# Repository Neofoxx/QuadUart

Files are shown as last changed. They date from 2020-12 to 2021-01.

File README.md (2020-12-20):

# QuadUart
A Quad UART to USB converter, based on PIC32.

## Overview

This project uses a PIC32MX564F128H micro to implement a quad UART-USB converter. The idea is to use an open-source toolchain to create a useful project, and one can **never** have too many UART converters

At least 4x 115200bps is supported, with plans to go to 4x 1Mbps, speed of the micro permitting.

Exposed pins are TX, RX, and DTR.

## Toolchain

The entire toolchain is open source:
- MCU definitions from the [SpicaStack](https://gitlab.com/spicastack/pic32-parts-free) project
- Compiler is GCC for mipsel crosscompiling. A ready-to-go package can be found [here](https://build.opensuse.org/package/show/home:neofoxx/gcc-mipsel-elf) (Ubuntu, Fedora, OpenSuse packges currently built)
- The USB stack is [M-stack](https://github.com/signal11/m-stack)
- PCB is provided as a set of Gerber files, and as a KiCAD project.

## TODO

- Add fiducails to PCB
- Add pinout to Readme
- License

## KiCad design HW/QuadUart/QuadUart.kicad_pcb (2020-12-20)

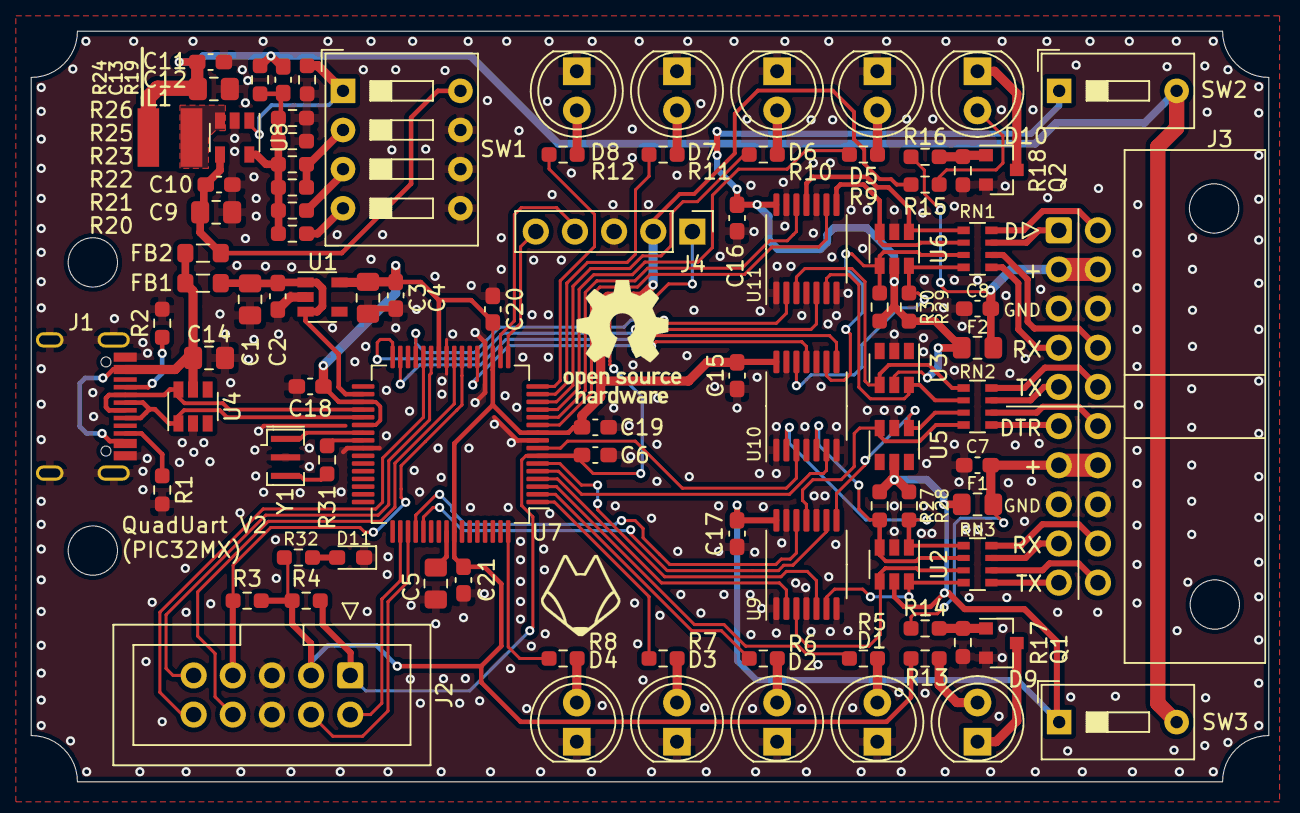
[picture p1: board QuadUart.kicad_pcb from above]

Board: 2 copper layers, 80.3 x 48.7 mm, 100 parts (1 on the bottom side), 92 nets.

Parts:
C1, C3, C9, C12: 4.7uF; C_0805_2012Metric_Pad1.18x1.45mm_HandSolder
C2, C4, C6, C7, C8, C10, C11, C15, C16, C17, C18, C19, C20, C21: 100nF; C_0603_1608Metric_Pad1.08x0.95mm_HandSolder
C5, C14: 10uF; C_0805_2012Metric_Pad1.18x1.45mm_HandSolder
C13: DNS; C_0603_1608Metric_Pad1.08x0.95mm_HandSolder
D1, D2, D3, D4, D5, D6, D7, D8, D9, D10: LED; LED_D5.0mm
D11: LED; LED_0603_1608Metric_Pad1.05x0.95mm_HandSolder
F1, F2: Polyfuse; Fuse_0805_2012Metric_Pad1.15x1.40mm_HandSolder
FB1, FB2: Ferrite_Bead_Small; L_0805_2012Metric_Pad1.05x1.20mm_HandSolder
H1, H2, H3, H4: MountingHole; MountingHole_3.2mm_M3
J1: USB_C_Receptacle_USB2.0; Jing USB C 2.0 16pin receptable
J2: Conn_02x05_Odd_Even; IDC-Header_2x05_P2.54mm_Vertical
J3: Conn_02x10_Odd_Even; IDC-Header_2x10_P2.54mm_Horizontal
J4: Conn_01x05; PinHeader_1x05_P2.54mm_Vertical
L1: 1.5uH; SMNR4018_(1616FPS)
LOGO1: Logo_Open_Hardware_Small; OSHW-Logo_7.5x8mm_SilkScreen
MARK1: LOGO; FOX_LOGO_MASK
MARK2: LOGO; FOX_LOGO_SILK
Q1, Q2: BC847; SOT-23
R1, R2: 5.1k; R_0603_1608Metric_Pad0.98x0.95mm_HandSolder
R3, R4, R19: 100k; R_0603_1608Metric_Pad0.98x0.95mm_HandSolder
R5, R6, R7, R8, R9, R10, R11, R12, R13, R15, R32: R; R_0603_1608Metric_Pad0.98x0.95mm_HandSolder
R14, R16, R17, R18: 10k; R_0603_1608Metric_Pad0.98x0.95mm_HandSolder
R20: 27k; R_0603_1608Metric_Pad0.98x0.95mm_HandSolder
R21: 180k; R_0603_1608Metric_Pad0.98x0.95mm_HandSolder
R22: 470k; R_0603_1608Metric_Pad0.98x0.95mm_HandSolder
R23: 330k; R_0603_1608Metric_Pad0.98x0.95mm_HandSolder
R24, R25, R26, R27, R28, R29, R30: 220k; R_0603_1608Metric_Pad0.98x0.95mm_HandSolder
R31: 0R; R_0603_1608Metric_Pad0.98x0.95mm_HandSolder
RN1, RN2, RN3: R_Pack04; R_Array_Convex_4x0603
SW1: SW_DIP_x04; SW_DIP_SPSTx04_Slide_9.78x12.34mm_W7.62mm_P2.54mm
SW2, SW3: SW_DIP_x01; SW_DIP_SPSTx01_Slide_9.78x4.72mm_W7.62mm_P2.54mm
U1: LN1134-3.3V; SOT-23-5
U2, U3, U4, U5, U6: SRV05-4; SOT-23-6
U7: PIC32MX564F128H; TQFP-64_10x10mm_P0.5mm
U8: BL8028; SOT-23-5
U9, U10, U11: SN74LV4T125; TSSOP-14_4.4x5mm_P0.65mm
Y1: Crystal_GND2; Resonator_SMD_muRata_CSTxExxV-3Pin_3.0x1.1mm

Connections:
+3V3: C3.1, C4.1, C15.1, C18.1, C19.1, C20.1, C21.1, J2.3, J4.2, R3.2, R4.2, R13.2, R15.2, R32.2, U1.5, U7.10, U7.19, U7.26, U7.35, U7.38, U7.57, U10.14
+5V: C1.1, C2.1, FB1.1, U1.1, U1.3, U7.34
/D+: J1.A6, J1.B6, U4.1, U7.37
/D-: J1.A7, J1.B7, U4.6, U7.36
/DTR_1: J3.11, RN2.5
/DTR_1_RES: RN2.4, U5.3, U9.11
/DTR_1_UC: U7.52, U9.12
/DTR_2: J3.12, RN2.6
/DTR_2_RES: RN2.3, U5.1, U9.8
/DTR_2_UC: U7.53, U9.9
/DTR_3: J3.1, RN1.7
/DTR_3_RES: RN1.2, U6.3, U11.8
/DTR_3_UC: U7.11, U11.9
/DTR_4: J3.2, RN1.8
/DTR_4_RES: RN1.1, U6.1, U11.11
/DTR_4_UC: U7.12, U11.12
/EN_1: R19.1, SW1.1, U8.1
/FB_1: C13.2, R20.1, R21.1, R22.1, R23.1, R24.2, R25.1, R26.1, U8.5
/LED_RX_1: R6.2, U7.2
/LED_RX_2: R8.2, U7.64
/LED_RX_3: R10.2, U7.14
/LED_RX_4: R12.2, U7.16
/LED_TX_1: R5.2, U7.3
/LED_TX_2: R7.2, U7.1
/LED_TX_3: R9.2, U7.13
/LED_TX_4: R11.2, U7.15
/OSC1: U7.39, Y1.1
/OSC2: R31.2, U7.40
/PGEC2: J4.5, U7.17
/PGED2: J4.4, U7.18
/PWR_1: C7.1, F1.1, J3.13, J3.14, R14.2
/PWR_2: C8.1, F2.1, J3.3, J3.4, R16.2
/RX_1: J3.17, RN3.7
/RX_1_RES: R27.2, RN3.2, U2.3, U10.5
/RX_1_UC: U7.5, U10.6
/RX_2: J3.18, RN3.8
/RX_2_RES: R28.2, RN3.1, U2.1, U10.2
/RX_2_UC: U7.8, U10.3
/RX_3: J3.7, RN1.5
/RX_3_RES: R29.2, RN1.4, U6.6, U10.12
/RX_3_UC: U7.31, U10.11
/RX_4: J3.8, RN1.6
/RX_4_RES: R30.2, RN1.3, U6.4, U10.9
/RX_4_UC: U7.21, U10.8
/RX_DBG: J2.2, U7.50
/SW_1_2.5V: R22.2, R23.2, SW1.2
/SW_1_3.3V: R21.2, SW1.3
/SW_1_5.0V: R20.2, SW1.4
/TCK: J2.9, U7.27
/TDI: J2.10, U7.28
/TDO: J2.8, U7.24
/TMS: J2.7, R3.1, U7.23
/TX_1: J3.19, RN3.5
/TX_1_RES: RN3.4, U2.6, U9.6
/TX_1_UC: U7.6, U9.5
/TX_2: J3.20, RN3.6
/TX_2_RES: RN3.3, U2.4, U9.3
/TX_2_UC: U7.4, U9.2
/TX_3: J3.9, RN2.7
/TX_3_RES: RN2.2, U3.6, U11.6
/TX_3_UC: U7.32, U11.5
/TX_4: J3.10, RN2.8
/TX_4_RES: RN2.1, U3.4, U11.3
/TX_4_UC: U7.29, U11.2
/TX_DBG: J2.4, U7.51
/VBUS: C14.1, FB1.2, FB2.2, J1.A4, U4.5
/VBUS_DCDC_5V: C9.1, C10.1, FB2.1, SW1.8, U8.4
/VCAP: C5.1, U7.56
/~MCLR~: C6.1, J2.1, J4.1, R4.1, U7.7
GND: C1.2, C2.2, C3.2, C4.2, C5.2, C6.2, C7.2, C8.2, C9.2, C10.2, C11.2, C12.2, C14.2, C15.2, C16.2, C17.2, C18.2, C19.2, C20.2, C21.2, D1.1, D2.1, D3.1, D4.1, D5.1, D6.1, D7.1, D8.1, D11.1, J1.A1, J1.S1, J2.5, J2.6, J3.5, J3.6, J3.15, J3.16, J4.3, Q1.2, Q2.2, R1.2, R2.2, R17.1, R18.1, R19.2, R25.2, R26.2, SW1.5, SW1.6, SW1.7, U1.2, U2.2, U3.2, U4.2, U5.2, U6.2, U7.9, U7.20, U7.25, U7.41, U8.2, U9.1, U9.4, U9.7, U9.10, U9.13, U10.1, U10.4, U10.7, U10.10, U10.13, U11.1, U11.4, U11.7, U11.10, U11.13, Y1.2
unnamed: C11.1, C12.1, C13.1, L1.2, R24.1, SW2.2, SW3.2
unnamed: D1.2, R5.1
unnamed: D2.2, R6.1
unnamed: D3.2, R7.1
unnamed: D4.2, R8.1
unnamed: D5.2, R9.1
unnamed: D6.2, R10.1
unnamed: D7.2, R11.1
unnamed: D8.2, R12.1
unnamed: D9.1, Q1.3
unnamed: D9.2, R13.1
unnamed: D10.1, Q2.3
unnamed: D10.2, R15.1
unnamed: D11.2, R32.1
unnamed: J1.A5, R2.1
unnamed: J1.B5, R1.1
unnamed: L1.1, U8.3
unnamed: Q1.1, R14.1, R17.2
unnamed: Q2.1, R16.1, R18.2
unnamed: R31.1, Y1.3
VCC: C17.1, F1.2, R27.1, R28.1, SW3.1, U2.5, U5.5, U9.14
VDD: C16.1, F2.2, R29.1, R30.1, SW2.1, U3.5, U6.5, U11.14

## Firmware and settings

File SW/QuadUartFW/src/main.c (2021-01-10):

#include <p32xxxx.h>
#include <inttypes.h>
#include <stdbool.h>
#include <builtin.h>

#include <string.h>
#include <stdio.h>
#include <newlib.h>
#include <errno.h>

// Config bits
#include <configBits.h>

// Drivers for HW
#include <GPIODrv.h>
#include <UARTDrv.h>
//#include <LED.h>
// USB
#include <usb.h>
#include <usb_config.h>
#include <usb_ch9.h>
#include <usb_cdc.h>
// COMMS - usb and UART
#include <COMMS.h>
// Interrupts
#include <interrupt.h>



#ifdef MULTI_CLASS_DEVICE
// Interfaces 0, 2, 4 and 6. Each begins at the IAD, and then goes on for 2 interfaces (0 and 1, 2 and 3, 4 and 5, 6 and 7).
static uint8_t cdc_interfaces[] = { 0, 2, 4, 6 };
#endif

static struct cdc_line_coding line_coding_1 =
{
	115200,
	CDC_CHAR_FORMAT_1_STOP_BIT,
	CDC_PARITY_NONE,
	8,
};

static struct cdc_line_coding line_coding_2 =
{
	115200,
	CDC_CHAR_FORMAT_1_STOP_BIT,
	CDC_PARITY_NONE,
	8,
};

static struct cdc_line_coding line_coding_3 =
{
	115200,
	CDC_CHAR_FORMAT_1_STOP_BIT,
	CDC_PARITY_NONE,
	8,
};

static struct cdc_line_coding line_coding_4 =
{
	115200,
	CDC_CHAR_FORMAT_1_STOP_BIT,
	CDC_PARITY_NONE,
	8,
};



volatile uint32_t packetCounter = 0;	// Reset by SOF. May be useful


// TODO - run the timer, like in MX440 example (SysTick style)
void simpleDelay(unsigned int noOfLoops){
    unsigned int i = 0;
    while (i<noOfLoops){
        i++;
        asm("nop");
    }
}

void setup(){
	// What is the equivalent of SYSTEMConfigPerformance?
	// -> Setting up the system for the required System Clock
	// -> Seting up the Wait States
	// -> Setting up PBCLK
	// -> Setting up Cache module (not presenf on MX1/2, but is on MX4)
	// Also of interest: https://microchipdeveloper.com/32bit:mx-arch-exceptions-processor-initialization
	// See Pic32 reference manual, for CP0 info http://ww1.microchip.com/downloads/en/devicedoc/61113e.pdf

	// DO NOT setup KSEG0 (cacheable area) on MX1/MX2, debugging will NOT work

	unsigned int val;
	val = _CP0_GET_CONFIG();	// Macro present in cp0defs.h
	val |= 0x00000003;	// Sets to KSEG0/cachable region, as per Table 2-11 in ref. manual
	_mtc0(_CP0_CONFIG, _CP0_CONFIG_SELECT, val);	// No macro, do it as suggested in first link.

	BMXCONbits.BMXWSDRM = 0;	// Set wait-states to 0 for Data Memory from SRAM

	CHECONbits.PFMWS = 2;		// Flash requires minimum 2 wait states at 61-80MHz

	CHECONbits.PREFEN = 1;		// Enable prefetch for cacheable PFM instructions

	GPIODrv_init();

	UARTDrv_1_Init(&line_coding_1);
	UARTDrv_2_Init(&line_coding_2);
	UARTDrv_3_Init(&line_coding_3);
	UARTDrv_4_Init(&line_coding_4);

	// Copied for USB, from hardware.c
	// TODO, make generic, make proper.
//#if defined (__32MX270F256D__)
//	IPC7bits.USBIP = 4;
//#elif defined(__32MX440F256H__)
//	IPC11bits.USBIP = 4;
//#endif

	// Enable USB interrupt
	IPC11bits.USBIP = 4;
	IPC11bits.USBIS = 0;
	// IEC bit is set in usb_hal.h


	// Enable DMA at the end.
	//DMACONbits.ON = 1;
	//asm("nop");

	// Enable interrupts - at the end, otherwise setting priorities is ineffective ? TODO

	// set the CP0 cause IV bit high
	// -> This tells the interrupt controller to use interrupts at ebase+0x200,
	// not the general exception at 0x180
	_CP0_BIS_CAUSE(_CP0_CAUSE_IV_MASK);

	// Enable multi-vectored mode
	INTCONSET = _INTCON_MVEC_MASK;

	// set the CP0 status IE bit high to turn on interrupts
	//INTEnableInterrupts();
	asm("ei");	// Compiler handles this, but should be same as _CP0_BIS_STATUS(_CP0_STATUS_IE_MASK)

}


int main(){

	uint32_t lastTime = _CP0_GET_COUNT();
	uint32_t currTime = lastTime;

	setup();
	cdc_set_interface_list(cdc_interfaces, 4);	// 4 UART interfaces...
	usb_init();

	for(;;){

		// Handle data that is to be sent to the PC
		// Nothing yet

		#ifndef USB_USE_INTERRUPTS
		usb_service();
		#endif


		currTime = _CP0_GET_COUNT();
		// Once per ms
		if ((currTime - lastTime) > ( (80000000 / 2) / 1000)){
			lastTime = currTime;
			// Fire ALL the RX interrupts, to get data that doesn't trigger the RX interrupt
			// Note, we will get interrupted by each interrupt
			if(UART_1_STA_bits.URXDA){
				UART_1_INT_IFS_bits.UART_1_INT_IFS_RXIF = 1;
			}
			if(UART_2_STA_bits.URXDA){
				UART_2_INT_IFS_bits.UART_2_INT_IFS_RXIF = 1;
			}
			if(UART_3_STA_bits.URXDA){
				UART_3_INT_IFS_bits.UART_3_INT_IFS_RXIF = 1;
			}
			if(UART_4_STA_bits.URXDA){
				UART_4_INT_IFS_bits.UART_4_INT_IFS_RXIF = 1;
			}

		}

	}

    return(0);
    
}




/////////////////////////////////////////////////////////////7

#ifdef USB_USE_INTERRUPTS
INTERRUPT(USB1Interrupt){
	usb_service();

	// All of the cases depend on this anyway.
	if (!usb_is_configured()){
		return;
	}

	// I forget, does this happen at 1ms, or at 125us?
	// 1ms is normal time slice, but we can send many more packets than just 1/ms... TODO check

	// Highest priority should be on Target->PC transmissions, since we can only buffer so much
	// For PC->Target, the USB stack auto-buffers, so there will be no dropouts

	// Total of 4 IN endpoints (Target->PC), and 4 OUT endpoints (PC->TARGET)

	// IN endpoints
	if (!usb_in_endpoint_halted(EP_UART_1) && !usb_in_endpoint_busy(EP_UART_1)){
		COMMS_USB_sendToPC(&comStruct_UART_1_RX, EP_UART_1, EP_UART_1_LEN);
	}
	if (!usb_in_endpoint_halted(EP_UART_2) && !usb_in_endpoint_busy(EP_UART_2)){
		COMMS_USB_sendToPC(&comStruct_UART_2_RX, EP_UART_2, EP_UART_2_LEN);
	}
	if (!usb_in_endpoint_halted(EP_UART_3) && !usb_in_endpoint_busy(EP_UART_3)){
		COMMS_USB_sendToPC(&comStruct_UART_3_RX, EP_UART_3, EP_UART_3_LEN);
	}
	if (!usb_in_endpoint_halted(EP_UART_4) && !usb_in_endpoint_busy(EP_UART_4)){
		COMMS_USB_sendToPC(&comStruct_UART_4_RX, EP_UART_4, EP_UART_4_LEN);
	}

	// OUT endpoints
	// When we get data, if TX interrupt isn't running, we reenable it. Note, that will interurpt us here.
	if (!usb_out_endpoint_halted(EP_UART_1) && usb_out_endpoint_has_data(EP_UART_1) && !usb_in_endpoint_busy(EP_UART_1)) {
		if(!COMMS_USB_recvFromPC(&comStruct_UART_1_TX, EP_UART_1)){
			if (!UART_1_INT_IEC_bits.UART_1_INT_IEC_TXIE){
				UART_1_INT_IEC_bits.UART_1_INT_IEC_TXIE = 1;
			}
		}
	}
	if (!usb_out_endpoint_halted(EP_UART_2) && usb_out_endpoint_has_data(EP_UART_2) && !usb_in_endpoint_busy(EP_UART_2)) {
		if(!COMMS_USB_recvFromPC(&comStruct_UART_2_TX, EP_UART_2)){
			if (!UART_2_INT_IEC_bits.UART_2_INT_IEC_TXIE){
				UART_2_INT_IEC_bits.UART_2_INT_IEC_TXIE = 1;
			}
		}
	}
	if (!usb_out_endpoint_halted(EP_UART_3) && usb_out_endpoint_has_data(EP_UART_3) && !usb_in_endpoint_busy(EP_UART_3)) {
		if(!COMMS_USB_recvFromPC(&comStruct_UART_3_TX, EP_UART_3)){
			if (!UART_3_INT_IEC_bits.UART_3_INT_IEC_TXIE){
				UART_3_INT_IEC_bits.UART_3_INT_IEC_TXIE = 1;
			}
		}
	}
	if (!usb_out_endpoint_halted(EP_UART_4) && usb_out_endpoint_has_data(EP_UART_4) && !usb_in_endpoint_busy(EP_UART_4)) {
		if(!COMMS_USB_recvFromPC(&comStruct_UART_4_TX, EP_UART_4)){
			if (!UART_4_INT_IEC_bits.UART_4_INT_IEC_TXIE){
				UART_4_INT_IEC_bits.UART_4_INT_IEC_TXIE = 1;
			}
		}
	}

}
#endif


/* Callbacks. These function names are set in usb_config.h. */
void app_set_configuration_callback(uint8_t configuration)
{

}

uint16_t app_get_device_status_callback()
{
	return 0x0000;
}

void app_endpoint_halt_callback(uint8_t endpoint, bool halted){
	// This is a notification only.  There is no way to reject this request.
}

int8_t app_set_interface_callback(uint8_t interface, uint8_t alt_setting){
	// The callback should return 0 if the new alternate setting can be set or -1 if
	// it cannot. This callback is completely unnecessary if you only have one
	// alternate setting (alternate setting zero) for each interface.
	return 0;
}

int8_t app_get_interface_callback(uint8_t interface){
	// The application should return the interface's current alternate setting
	return 0;
}

void app_out_transaction_callback(uint8_t endpoint){
	// If we wanted, we can use this function to trigger when the
	// OUT transaction on the endpoint is finished (PC->us), and read
	// data out fast that way. Unnecessary for now.
}

void app_in_transaction_complete_callback(uint8_t endpoint){
	// If we wanted, we can use this function to trigger when the
	// IN transaction on the endpoint is finished (us->PC), and rearm/send
	// data fast that way. Unnecessary for now.
}

int8_t app_unknown_setup_request_callback(const struct setup_packet *setup){
	/* To use the CDC device class, have a handler for unknown setup
	 * requests and call process_cdc_setup_request() (as shown here),
	 * which will check if the setup request is CDC-related, and will
	 * call the CDC application callbacks defined in usb_cdc.h. For
	 * composite devices containing other device classes, make sure
	 * MULTI_CLASS_DEVICE is defined in usb_config.h and call all
	 * appropriate device class setup request functions here.
	 */
	// Since we only use (dual) CDC, cdc_setup_request is enough, it gets called twise.
	return process_cdc_setup_request(setup);
}

int16_t app_unknown_get_descriptor_callback(const struct setup_packet *pkt, const void **descriptor){
	// Called when a GET_DESCRIPTOR request is received from
	// the host for a descriptor which is unrecognized by the USB stack.
	return -1;
}

void app_start_of_frame_callback(void){
	// Interrupt at SOF
	packetCounter = 0;
}

void app_usb_reset_callback(void){
	// Possibly reset USB buffer, or setup DMAs or something.
	// Unnecessary for now.
}

/* CDC Callbacks. See usb_cdc.h for documentation. */

int8_t app_send_encapsulated_command(uint8_t interface, uint16_t length){
	// Unsure what to support here.
	return -1;
}

int16_t app_get_encapsulated_response(uint8_t interface,
                                      uint16_t length, const void **report,
                                      usb_ep0_data_stage_callback *callback,
                                      void **context){
	// Unsure what to support here.
	return -1;
}

int8_t app_set_comm_feature_callback(uint8_t interface,
                                     bool idle_setting,
                                     bool data_multiplexed_state)
{
	return -1;
}

int8_t app_clear_comm_feature_callback(uint8_t interface,
                                       bool idle_setting,
                                       bool data_multiplexed_state)
{
	return -1;
}

int8_t app_get_comm_feature_callback(uint8_t interface,
                                     bool *idle_setting,
                                     bool *data_multiplexed_state)
{
	return -1;
}

int8_t app_set_line_coding_callback(uint8_t interface,
                                    const struct cdc_line_coding *coding)
{
	// Check if values are in ranges we support
	if (coding->dwDTERate <= 1000000
			&& (coding->bCharFormat == CDC_CHAR_FORMAT_1_STOP_BIT || coding->bCharFormat == CDC_CHAR_FORMAT_2_STOP_BITS)
			&& coding->bParityType == CDC_PARITY_NONE
			&& coding->bDataBits == 8){

		if (interface == 0){
			line_coding_1 = *coding;
			UARTDrv_1_Init(&line_coding_1);
		}
		if (interface == 2){
			line_coding_2 = *coding;
			UARTDrv_2_Init(&line_coding_2);
		}
		if (interface == 4){
			line_coding_3 = *coding;
			UARTDrv_3_Init(&line_coding_3);
		}
		if (interface == 6){
			line_coding_4 = *coding;
			UARTDrv_4_Init(&line_coding_4);
		}

	}

	return 0;	// No way to deny. Must return 0, otherwise it will stall.
}

int8_t app_get_line_coding_callback(uint8_t interface,
                                    struct cdc_line_coding *coding)
{
	// Return what sort of line_coding we are using.
	if (interface == 0){
		*coding = line_coding_1;
	}
	else if (interface == 2){
		*coding = line_coding_2;
	}
	else if (interface == 4){
		*coding = line_coding_3;
	}
	else if (interface == 6){
		*coding = line_coding_4;
	}

	return 0;
}

int8_t app_set_control_line_state_callback(uint8_t interface,
                                           bool dtr, bool rts)
{
	// Set DTR and RTS lines, according to demands.
	// Only interface 2 (UART) supports this

	if (interface == 0){
		GPIODrv_setDTR_1(dtr);
	}
	else if (interface == 2){
		GPIODrv_setDTR_2(dtr);
	}
	else if (interface == 4){
		GPIODrv_setDTR_3(dtr);
	}
	else if (interface == 6){
		GPIODrv_setDTR_4(dtr);
	}


	return 0;
}

int8_t app_send_break_callback(uint8_t interface, uint16_t duration)
{
	return 0;
}

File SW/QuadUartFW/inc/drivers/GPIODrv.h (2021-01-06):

#ifndef GPIODRV_H_88e635eabb0f41b7aa44dc94a480edfc
#define GPIODRV_H_88e635eabb0f41b7aa44dc94a480edfc

#include <p32xxxx.h>
#include <inttypes.h>
#include <stdbool.h>


// ICSP pins -------------------------------------------------------------------
// PGEC - analog pin
#define ICSP_PGEC_TRISbits		TRISBbits
#define ICSP_PGEC_TRISPIN		TRISB6
#define ICSP_PGEC_LATbits		LATBbits
#define ICSP_PGEC_LATPIN		LATB6
#define ICSP_PGEC_MASK			(1<<6)
#define ICSP_PGEC_ANSELbits		AD1PCFGbits
#define ICSP_PGEC_ANSELBIT		PCFG6

// PGED - analog pin
#define ICSP_PGED_TRISbits		TRISBbits
#define ICSP_PGED_TRISPIN		TRISB7
#define ICSP_PGED_LATbits		LATBbits
#define ICSP_PGED_LATPIN		LATB7
#define ICSP_PGED_MASK			(1<<7)
#define ICSP_PGED_ANSELbits		AD1PCFGbits
#define ICSP_PGED_ANSELBIT		PCFG7
// -----------------------------------------------------------------------------



// JTAG pins -------------------------------------------------------------------
// TMS - analog pin
#define JTAG_TMS_TRISbits		TRISBbits
#define JTAG_TMS_TRISPIN		TRISB10
#define JTAG_TMS_LATbits		LATBbits
#define JTAG_TMS_LATPIN			LATB10
#define JTAG_TMS_MASK			(1<<10)
#define JTAG_TMS_ANSELbits		AD1PCFGbits
#define JTAG_TMS_ANSELBIT		PCFG10

// TCK - analog pin
#define JTAG_TCK_TRISbits		TRISBbits
#define JTAG_TCK_TRISPIN		TRISB12
#define JTAG_TCK_LATbits		LATBbits
#define JTAG_TCK_LATPIN			LATB12
#define JTAG_TCK_MASK			(1<<12)
#define JTAG_TCK_ANSELbits		AD1PCFGbits
#define JTAG_TCK_ANSELBIT		PCFG12

// TDI - analog pin
#define JTAG_TDI_TRISbits		TRISBbits
#define JTAG_TDI_TRISPIN		TRISB13
#define JTAG_TDI_LATbits		LATBbits
#define JTAG_TDI_LATPIN			LATB13
#define JTAG_TDI_MASK			(1<<13)
#define JTAG_TDI_ANSELbits		AD1PCFGbits
#define JTAG_TDI_ANSELBIT		PCFG13

// TDO - analog pin
#define JTAG_TDO_TRISbits		TRISBbits
#define JTAG_TDO_TRISPIN		TRISB11
#define JTAG_TDO_LATbits		LATBbits
#define JTAG_TDO_LATPIN			LATB11
#define JTAG_TDO_MASK			(1<<11)
#define JTAG_TDO_ANSELbits		AD1PCFGbits
#define JTAG_TDO_ANSELBIT		PCFG11

// -----------------------------------------------------------------------------

// LEDs ------------------------------------------------------------------------
// Bottom side
// TX 1 - closest to connector
#define LED_1_TX_TRISbits		TRISEbits
#define LED_1_TX_TRISPIN		TRISE7
#define LED_1_TX_LATbits		LATEbits
#define LED_1_TX_LATPIN			LATE7
#define LED_1_TX_LATINV			LATEINV
#define LED_1_TX_MASK			(1<<7)

// RX 1 - 2nd closest to connector
#define LED_1_RX_TRISbits		TRISEbits
#define LED_1_RX_TRISPIN		TRISE6
#define LED_1_RX_LATbits		LATEbits
#define LED_1_RX_LATPIN			LATE6
#define LED_1_RX_LATINV			LATEINV
#define LED_1_RX_MASK			(1<<6)

// TX 2 - 3rd closest to connector
#define LED_2_TX_TRISbits		TRISEbits
#define LED_2_TX_TRISPIN		TRISE5
#define LED_2_TX_LATbits		LATEbits
#define LED_2_TX_LATPIN			LATE5
#define LED_2_TX_LATINV			LATEINV
#define LED_2_TX_MASK			(1<<5)

// RX 2 - farthest from connector
#define LED_2_RX_TRISbits		TRISEbits
#define LED_2_RX_TRISPIN		TRISE4
#define LED_2_RX_LATbits		LATEbits
#define LED_2_RX_LATPIN			LATE4
#define LED_2_RX_LATINV			LATEINV
#define LED_2_RX_MASK			(1<<4)

// Top side - these are ALL on analog ports... Disabled by writing a 1 into AD1PCFG at the ANx place
// ANx and the pin location conincide, so reuse mask
// Defined as ANSEL, as that is more commonly used
// TX 3 - closest to connector
#define LED_3_TX_TRISbits		TRISBbits
#define LED_3_TX_TRISPIN		TRISB3
#define LED_3_TX_LATbits		LATBbits
#define LED_3_TX_LATPIN			LATB3
#define LED_3_TX_LATINV			LATBINV
#define LED_3_TX_MASK			(1<<3)
#define LED_3_TX_ANSELbits		AD1PCFGbits
#define LED_3_TX_ANSELBIT		PCFG3

// RX 3 - 2nd closest to connector
#define LED_3_RX_TRISbits		TRISBbits
#define LED_3_RX_TRISPIN		TRISB2
#define LED_3_RX_LATbits		LATBbits
#define LED_3_RX_LATPIN			LATB2
#define LED_3_RX_LATINV			LATBINV
#define LED_3_RX_MASK			(1<<2)
#define LED_3_RX_ANSELbits		AD1PCFGbits
#define LED_3_RX_ANSELBIT		PCFG2

// TX 4 - 3rd closest to connector
#define LED_4_TX_TRISbits		TRISBbits
#define LED_4_TX_TRISPIN		TRISB1
#define LED_4_TX_LATbits		LATBbits
#define LED_4_TX_LATPIN			LATB1
#define LED_4_TX_LATINV			LATBINV
#define LED_4_TX_MASK			(1<<1)
#define LED_4_TX_ANSELbits		AD1PCFGbits
#define LED_4_TX_ANSELBIT		PCFG1

// RX 4 - farthest from connector
#define LED_4_RX_TRISbits		TRISBbits
#define LED_4_RX_TRISPIN		TRISB0
#define LED_4_RX_LATbits		LATBbits
#define LED_4_RX_LATPIN			LATB0
#define LED_4_RX_LATINV			LATBINV
#define LED_4_RX_MASK			(1<<0)
#define LED_4_RX_ANSELbits		AD1PCFGbits
#define LED_4_RX_ANSELBIT		PCFG0

// -----------------------------------------------------------------------------




// UARTs -----------------------------------------------------------------------
// Debug UART - UART1
#define UART_DBG_TX_TRISbits		TRISDbits
#define UART_DBG_TX_TRISPIN			TRISD3
#define UART_DBG_TX_LATbits			LATDbits
#define UART_DBG_TX_LATPIN			LATD3
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

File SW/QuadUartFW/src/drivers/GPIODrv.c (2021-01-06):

#include <p32xxxx.h>
#include <GPIODrv.h>
#include <inttypes.h>

// TRIS bits - 1 is input, 0 is output
// "ANSEL" / AD1PCFGbits bits - 0 is analog, 1 is digital. Default is analog!

void GPIODrv_init(){
	// Prepare ALL GPIO inputs, even if then redefined/reused in other modules


	// JTAG & ICSP pins
	// When in DEBUG, can/should leave unconfigured
	// When not in DEBUG, either configure as analog inputs, or as digital outputs
	// -> Except TMS, which can be an input due to an external pull-up resistor
	// For JTAG, might need to check how to disable JTAG pins... (TODO)
#if !defined(DEBUG)
	// ICSP
	ICSP_PGEC_ANSELbits.ICSP_PGEC_ANSELBIT = 1;		// Digital pin
	ICSP_PGEC_TRISbits.ICSP_PGEC_TRISPIN = 0;		// Digital output
	ICSP_PGEC_LATbits.ICSP_PGEC_LATPIN = 0;			// Set to 0

	ICSP_PGED_ANSELbits.ICSP_PGED_ANSELBIT = 1;		// Digital pin
	ICSP_PGED_TRISbits.ICSP_PGED_TRISPIN = 0;		// Digital output
	ICSP_PGED_LATbits.ICSP_PGED_LATPIN = 0;			// Set to 0

	// JTAG
	JTAG_TMS_ANSELbits.JTAG_TMS_ANSELBIT = 1;		// Digital pin
	JTAG_TMS_TRISbits.JTAG_TMS_TRISPIN = 1;			// Digital output

	JTAG_TCK_ANSELbits.JTAG_TCK_ANSELBIT = 1;		// Digital pin
	JTAG_TCK_TRISbits.JTAG_TCK_TRISPIN = 0;			// Digital output
	JTAG_TCK_LATbits.JTAG_TCK_LATPIN = 0;			// Set to 0

	JTAG_TDI_ANSELbits.JTAG_TDI_ANSELBIT = 1;		// Digital pin
	JTAG_TDI_TRISbits.JTAG_TDI_TRISPIN = 0;			// Digital output
	JTAG_TDI_LATbits.JTAG_TDI_LATPIN = 0;			// Set to 0

	JTAG_TDO_ANSELbits.JTAG_TDO_ANSELBIT = 1;		// Digital pin
	JTAG_TDO_TRISbits.JTAG_TDO_TRISPIN = 0;			// Digital output
	JTAG_TDO_LATbits.JTAG_TDO_LATPIN = 0;			// Set to 0
#endif



	// LEDs
	// Setup as outputs and turn off
	LED_1_TX_TRISbits.LED_1_TX_TRISPIN = 0;			// Digital output
	LED_1_TX_LATbits.LED_1_TX_LATPIN = 0;			// Set to 0

	LED_1_RX_TRISbits.LED_1_RX_TRISPIN = 0;			// Digital output
	LED_1_RX_LATbits.LED_1_RX_LATPIN = 0;			// Set to 0

	LED_2_TX_TRISbits.LED_2_TX_TRISPIN = 0;			// Digital output
	LED_2_TX_LATbits.LED_2_TX_LATPIN = 0;			// Set to 0

	LED_2_RX_TRISbits.LED_2_RX_TRISPIN = 0;			// Digital output
	LED_2_RX_LATbits.LED_2_RX_LATPIN = 0;			// Set to 0

	LED_3_TX_ANSELbits.LED_3_TX_ANSELBIT = 1;		// Digital pin
	LED_3_TX_TRISbits.LED_3_TX_TRISPIN = 0;			// Digital output
	LED_3_TX_LATbits.LED_3_TX_LATPIN = 0;			// Set to 0

	LED_3_RX_ANSELbits.LED_3_RX_ANSELBIT = 1;		// Digital pin
	LED_3_RX_TRISbits.LED_3_RX_TRISPIN = 0;			// Digital output
	LED_3_RX_LATbits.LED_3_RX_LATPIN = 0;			// Set to 0

	LED_4_TX_ANSELbits.LED_4_TX_ANSELBIT = 1;		// Digital pin
	LED_4_TX_TRISbits.LED_4_TX_TRISPIN = 0;			// Digital output
	LED_4_TX_LATbits.LED_4_TX_LATPIN = 0;			// Set to 0

	LED_4_RX_ANSELbits.LED_4_RX_ANSELBIT = 1;		// Digital pin
	LED_4_RX_TRISbits.LED_4_RX_TRISPIN = 0;			// Digital output
	LED_4_RX_LATbits.LED_4_RX_LATPIN = 0;			// Set to 0


	// UARTs
	// Setup as outpus and high (TX, DTR), or as inputs (RX)
	UART_1_TX_TRISbits.UART_1_TX_TRISPIN = 0;		// Digital output
	UART_1_TX_LATbits.UART_1_TX_LATPIN = 1;			// Set to 1

	UART_1_RX_TRISbits.UART_1_RX_TRISPIN = 1;		// Set to input

	UART_1_DTR_TRISbits.UART_1_DTR_TRISPIN = 0;		// Digital output
	UART_1_DTR_LATbits.UART_1_DTR_LATPIN = 1;		// Set to 1 (probably)


	UART_2_TX_TRISbits.UART_2_TX_TRISPIN = 0;		// Digital output
	UART_2_TX_LATbits.UART_2_TX_LATPIN = 1;			// Set to 1

	UART_2_RX_TRISbits.UART_2_RX_TRISPIN = 1;		// Set to input

	UART_2_DTR_TRISbits.UART_2_DTR_TRISPIN = 0;		// Digital output
	UART_2_DTR_LATbits.UART_2_DTR_LATPIN = 1;		// Set to 1 (probably)


	UART_3_TX_TRISbits.UART_3_TX_TRISPIN = 0;		// Digital output
	UART_3_TX_LATbits.UART_3_TX_LATPIN = 1;			// Set to 1

	UART_3_RX_TRISbits.UART_3_RX_TRISPIN = 1;		// Set to input

	UART_3_DTR_ANSELbits.UART_3_DTR_ANSELBIT = 1;	// Digital pin
	UART_3_DTR_TRISbits.UART_3_DTR_TRISPIN = 0;		// Digital output
	UART_3_DTR_LATbits.UART_3_DTR_LATPIN = 1;		// Set to 1 (probably)


	UART_4_TX_TRISbits.UART_4_TX_TRISPIN = 0;		// Digital output
	UART_4_TX_LATbits.UART_4_TX_LATPIN = 1;			// Set to 1

	UART_4_RX_TRISbits.UART_4_RX_TRISPIN = 1;		// Set to input

	UART_4_DTR_ANSELbits.UART_4_DTR_ANSELBIT = 1;	// Digital pin
	UART_4_DTR_TRISbits.UART_4_DTR_TRISPIN = 0;		// Digital output
	UART_4_DTR_LATbits.UART_4_DTR_LATPIN = 1;		// Set to 1 (probably)



}


void GPIODrv_setDTR_1(bool state){
	UART_1_DTR_LATbits.UART_1_DTR_LATPIN = state;
}

void GPIODrv_setDTR_2(bool state){
	UART_2_DTR_LATbits.UART_2_DTR_LATPIN = state;
}

void GPIODrv_setDTR_3(bool state){
	UART_3_DTR_LATbits.UART_3_DTR_LATPIN = state;
}

void GPIODrv_setDTR_4(bool state){
	UART_4_DTR_LATbits.UART_4_DTR_LATPIN = state;
}

void GPIODrv_setLED_1_TX(bool state){
	LED_1_TX_LATbits.LED_1_TX_LATPIN = state;
}
void GPIODrv_setLED_1_RX(bool state){
	LED_1_RX_LATbits.LED_1_RX_LATPIN = state;
}
void GPIODrv_setLED_2_TX(bool state){
	LED_2_TX_LATbits.LED_2_TX_LATPIN = state;
}
void GPIODrv_setLED_2_RX(bool state){
	LED_2_RX_LATbits.LED_2_RX_LATPIN = state;
}
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

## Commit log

2020-11-28 Mid-work commit. Dimensions and placement done
    [QuadUart.kicad_pcb, QuadUart.sch]
2020-11-29 Finished layout, added Gerbers
    [QuadUart-B_Cu.gbl, QuadUart-B_Mask.gbs, QuadUart-B_SilkS.gbo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]
2020-12-06 Added 2 capacitors (ESD) and changed fuse position.
    [QuadUart.kicad_pcb, QuadUart.sch]
2020-12-06 Modified silkscreen. Exported gerbers
    [QuadUart-B_Cu.gbl, QuadUart-B_Mask.gbs, QuadUart-B_SilkS.gbo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]
2020-12-06 On close change
    [QuadUart.kicad_pcb]
2020-12-20 Fixed Input/output swap on buffers, increased to V2
    [QuadUart-B_Cu.gbl, QuadUart-B_Mask.gbs, QuadUart-B_SilkS.gbo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]
2020-12-20 Update README, add LICENSE file, add whatever was from autosave of PCB
2021-01-03 First SW commit. Compiles and shows 2 UARTS for now
2021-01-07 Mid-work commit. Now shows up as 4 devices
2021-01-10 First version of multiple UARTs working, loopback test OK, has some issues with opening/closing
    [COMMS.c, UARTDrv.c, main.c]
